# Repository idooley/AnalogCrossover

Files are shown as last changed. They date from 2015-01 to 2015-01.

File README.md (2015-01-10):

## Overview
This repo contains various things that were used to help in the design and building of an analog active 3-way 12dB/octave crossover (woofer, midrange, tweeter) with delays. In my project I configure the circuits to crossover at 125Hz and 2.7KHz. The crossover can be adapted to any audio frequencies by changing the capacitor and resistor values.

Some things you'll find in the repo:
* python utilities for help in selecting optimal capacitor and resistor values for a Sallen-Key topology active filter. To crossover at different frequencies, different combinations of resistors and capactitors may be used. Lower value resistors will reduce the Johnson Noise introduced into the signal by the resistors. Lower valued capacitors are likely to be cheaper. Finding a good combination of values that produce the desired crossover frequencies is a non-trivial exercise.
* DipTrace schematic files and PCB layouts
* PCB gerbers (both for the crossover circuit PCB and a corresponding dual-rail power supply)
* Pictures of the results
* LTSpice files for parts of the crossover design
* Bill Of Materials containing DigiKey part numbers that I used in this DIY project

## Background
The design is based off a design contained in <a href="http://www.amazon.com/Design-Active-Crossovers-Douglas-Self/dp/0240817389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">Douglas Self's excellent book "The Design of Active Crossovers"</a>.

The crossover can use either the solid NE5532 opamps or 10x more expensive, and more modern, LM4562 opamps (or a combination of both). I chose to use the LM4562's for the input stage and NE5532's for the filter and delay stages.
 
## Isaac's DIY Project

The nearly final product of this DIY product consists of these two working crossover/delay boards and their power supply:

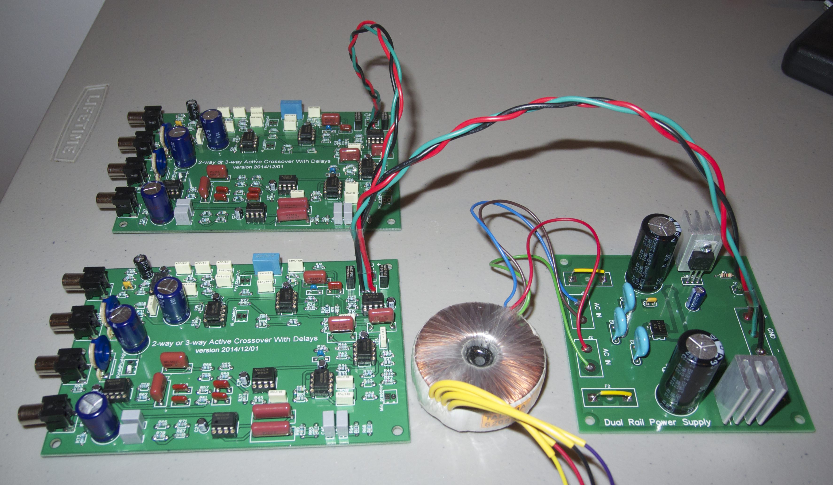
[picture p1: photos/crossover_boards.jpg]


Now I just need to put these in an enclosure of some kind (and add those two missing fuses you may have noticed in the picture). After doing this I'll measure the frequency response and noise floor more carefully.

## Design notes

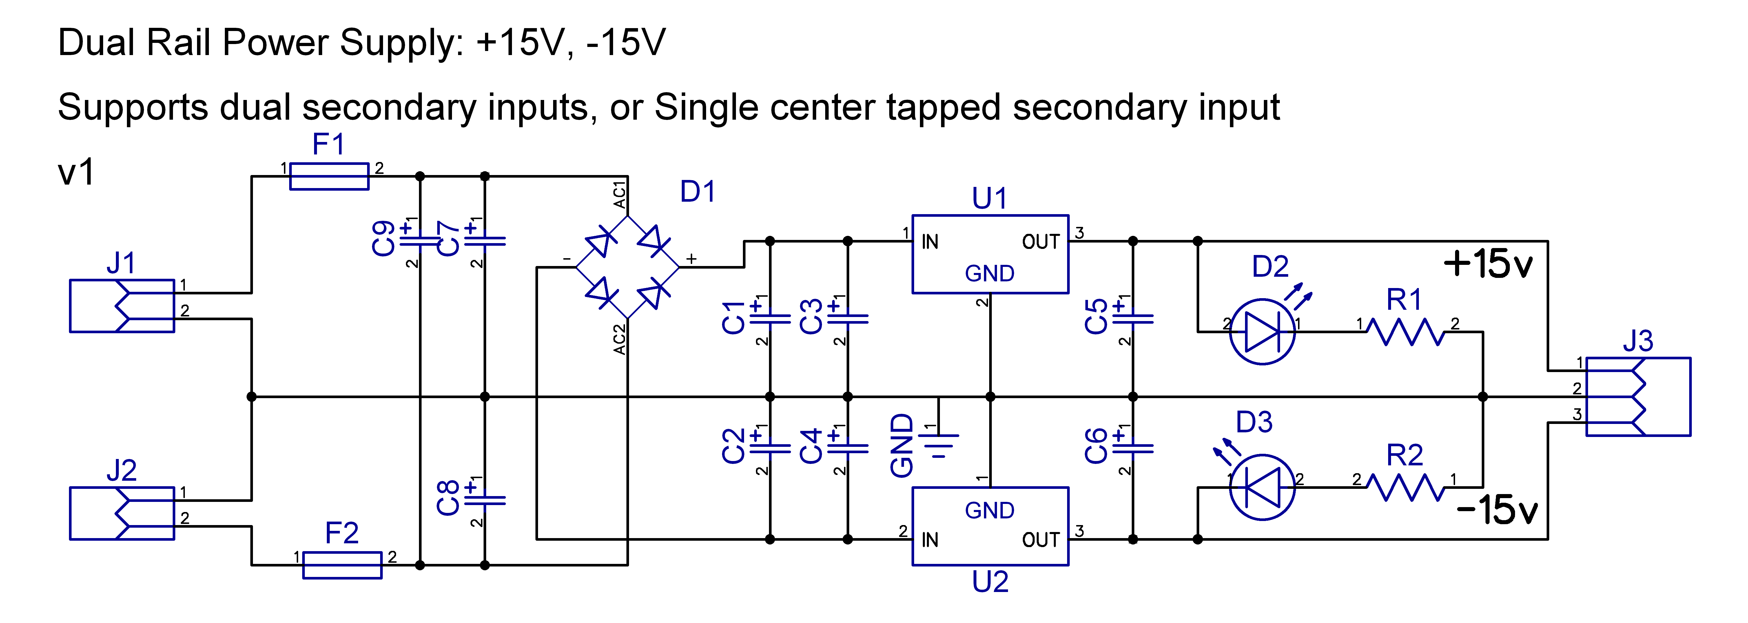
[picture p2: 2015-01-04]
power supply schematic.png

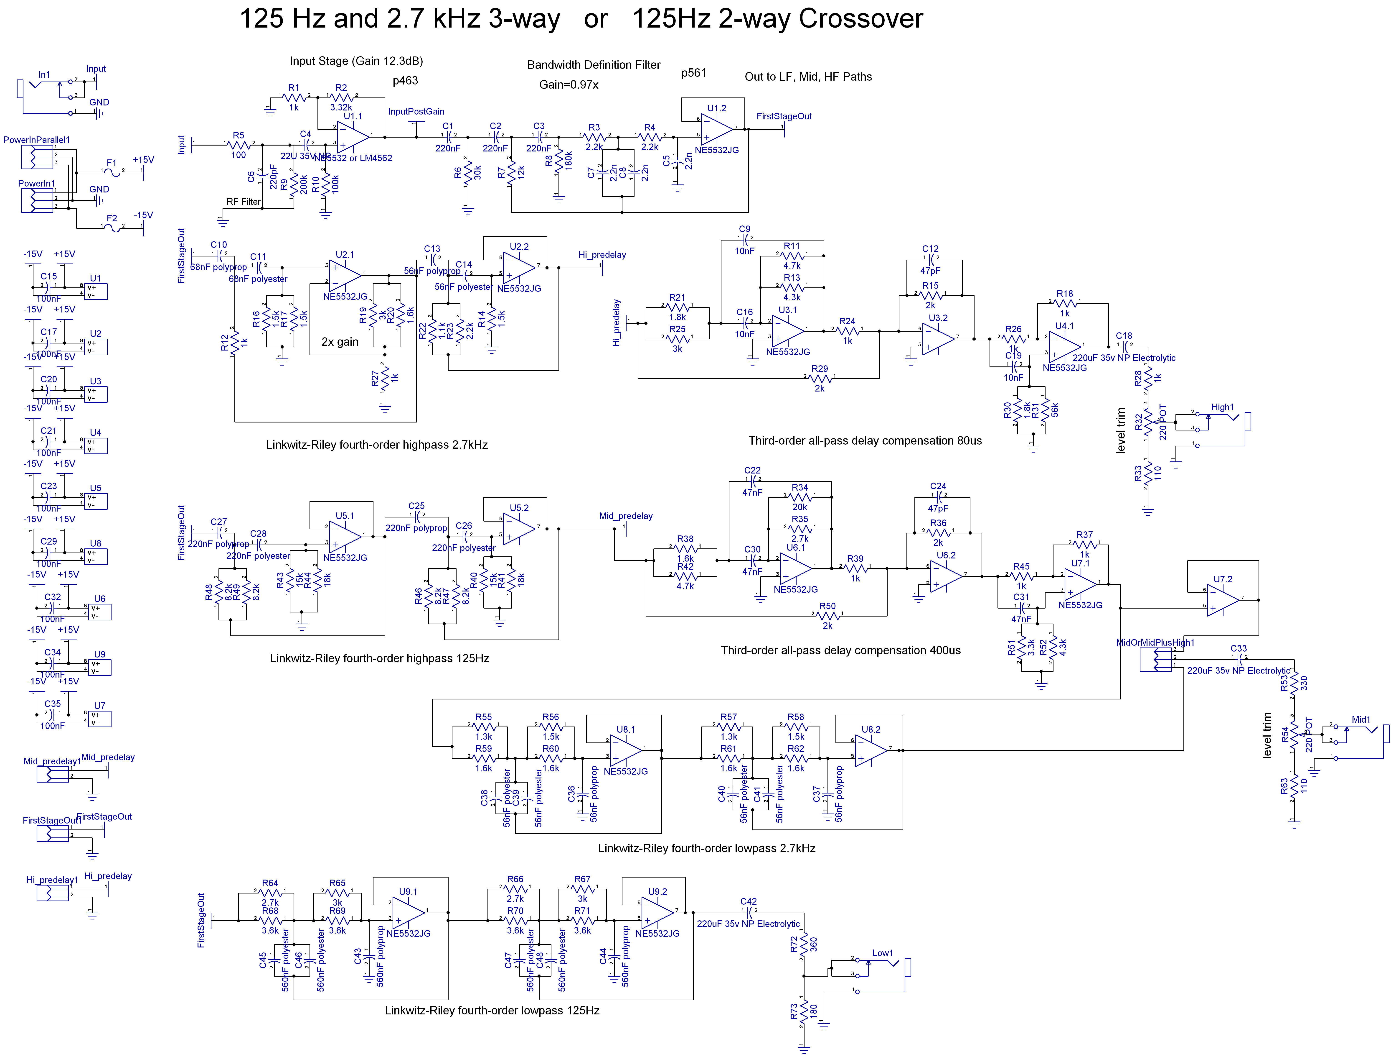
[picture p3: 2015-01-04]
schematic-800dpi.png

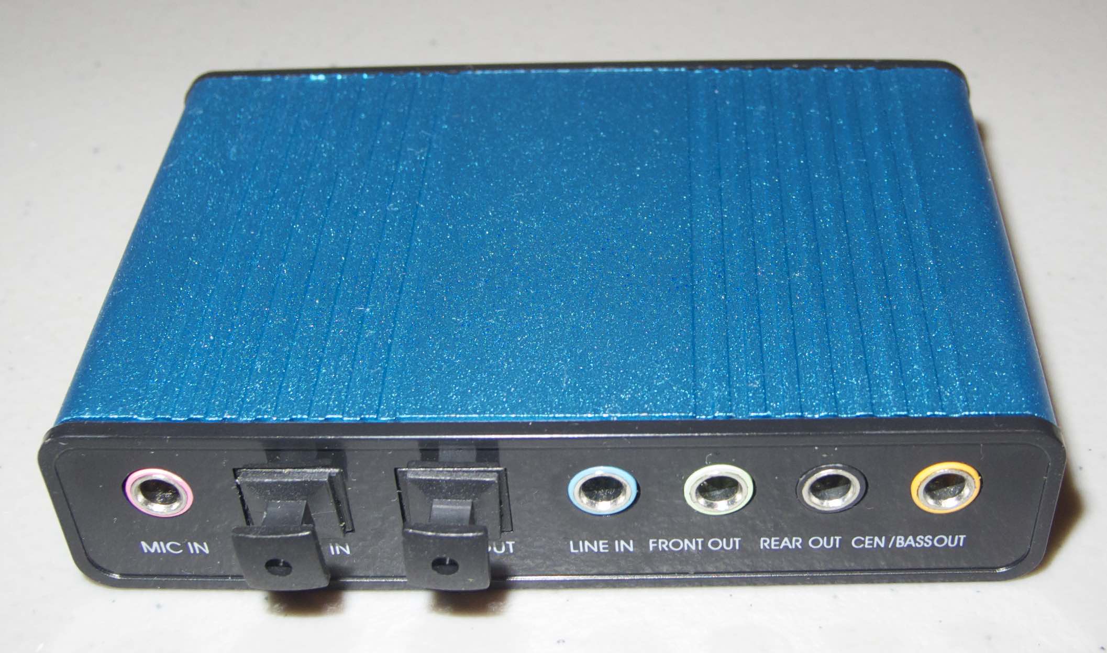
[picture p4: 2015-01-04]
photos/USB_SoundCard.jpg

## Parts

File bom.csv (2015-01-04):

RefDes | Value | Part
C1 | 220nF | 399-9686-ND
C2 | 220nF | 399-9686-ND
C3 | 220nF | 399-9686-ND
C4 | 22U 35V NP | 493-6093-ND
C5 | 2.2n | 399-9692-1-ND
C6 | 220pF | 478-4847-ND
C7 | 2.2n | 399-9692-1-ND
C8 | 2.2n | 399-9692-1-ND
C9 | 10nF | 399-5872-ND
C10 | 68nF polyprop | 495-1292-ND
C11 | 68nF polyester | 399-6036-ND
C12 | 47pF | 445-4722-ND
C13 | 56nF polyprop | P12080-ND
C14 | 56nF polyester | P4522-ND
C15 | 100nF | 493-5955-ND
C16 | 10nF | 399-5872-ND
C17 | 100nF | 493-5955-ND
C18 | 220uF 35v NP Electrolytic | P1192-ND
C19 | 10nF | 399-5872-ND
C20 | 100nF | 493-5955-ND
C21 | 100nF | 493-5955-ND
C22 | 47nF | 399-5873-ND
C23 | 100nF | 493-5955-ND
C24 | 47pF | 445-4722-ND
C25 | 220nF polyprop | P16711-ND
C26 | 220nF polyester | 399-9686-ND
C27 | 220nF polyprop | P16711-ND
C28 | 220nF polyester | 399-9686-ND
C29 | 100nF | 493-5955-ND
C30 | 47nF | 399-5873-ND
C31 | 47nF | 399-5873-ND
C32 | 100nF | 493-5955-ND
C33 | 220uF 35v NP Electrolytic | P1192-ND
C34 | 100nF | 493-5955-ND
C35 | 100nF | 493-5955-ND
C36 | 56nF polyprop | P12080-ND
C37 | 56nF polyprop | P12080-ND
C38 | 56nF polyester | P4522-ND
C39 | 56nF polyester | P4522-ND
C40 | 56nF polyester | P4522-ND
C41 | 56nF polyester | P4522-ND
C42 | 220uF 35v NP Electrolytic | P1192-ND
C43 | 560nF polyprop | PCF1604-ND
C44 | 560nF polyprop | PCF1604-ND
C45 | 560nF polyester | BC1634-ND
C46 | 560nF polyester | BC1634-ND
C47 | 560nF polyester | BC1634-ND
C48 | 560nF polyester | BC1634-ND
F1 |  | 507-1173-ND
F2 |  | 507-1173-ND
High1 |  | PJRAN1X1U01X
In1 |  | PJRAN1X1U01X
Low1 |  | PJRAN1X1U01X
Mid1 |  | PJRAN1X1U01X
R1 | 1k | RNF18FTD1K00CT-ND
R2 | 3.32k | RNF18FTD3K32CT-ND
R3 | 2.2k | S2.2KCACT-ND
R4 | 2.2k | S2.2KCACT-ND
R5 | 100 | RNF18FTD100RCT-ND
R6 | 30k | S30KCACT-ND
R7 | 12k | S12KCACT-ND
R8 | 180k | S180KCACT-ND
R9 | 200k | RNF18FTD200KCT-ND
R10 | 100k | RNF18FTD100KCT-ND
R11 | 4.7k | S4.7KCACT-ND
R12 | 1k | RNF18FTD1K00CT-ND
R13 | 4.3k | S4.3KCACT-ND
R14 | 1.5k | S1.5KCACT-ND
R15 | 2k | S2KCACT-ND
R16 | 1.5k | S1.5KCACT-ND
R17 | 1.5k | S1.5KCACT-ND
R18 | 1k | RNF18FTD1K00CT-ND
R19 | 3k | S3KCACT-ND
R20 | 1.6k | S1.6KCACT-ND
R21 | 1.8k | S1.8KCACT-ND
R22 | 1.1k | S1.1KCACT-ND
R23 | 2.2k | S2.2KCACT-ND
R24 | 1k | RNF18FTD1K00CT-ND
R25 | 3k | S3KCACT-ND
R26 | 1k | RNF18FTD1K00CT-ND
R27 | 1k | RNF18FTD1K00CT-ND
R28 | 1k | RNF18FTD1K00CT-ND
R29 | 2k | S2KCACT-ND
R30 | 1.8k | S1.8KCACT-ND
R31 | 56k | S56KCACT-ND
R32 | 220 POT | 201XR251B-ND
R33 | 110 | S110CACT-ND
R34 | 20k | S20KCACT-ND
R35 | 2.7k | S2.7KCACT-ND
R36 | 2k | S2KCACT-ND
R37 | 1k | RNF18FTD1K00CT-ND
R38 | 1.6k | S1.6KCACT-ND
R39 | 1k | RNF18FTD1K00CT-ND
R40 | 15k | S15KCACT-ND
R41 | 18k | S18KCACT-ND
R42 | 4.7k | S4.7KCACT-ND
R43 | 15k | S15KCACT-ND
R44 | 18k | S18KCACT-ND
R45 | 1k | RNF18FTD1K00CT-ND
R46 | 8.2k | S8.2KCACT-ND
R47 | 8.2k | S8.2KCACT-ND
R48 | 8.2k | S8.2KCACT-ND
R49 | 8.2k | S8.2KCACT-ND
R50 | 2k | S2KCACT-ND
R51 | 3.3k | S3.3KCACT-ND
R52 | 4.3k | S4.3KCACT-ND
R53 | 330 | S330CACT-ND
R54 | 220 POT | 201XR251B-ND
R55 | 1.3k | S1.3KCACT-ND
R56 | 1.5k | S1.5KCACT-ND
R57 | 1.3k | S1.3KCACT-ND
R58 | 1.5k | S1.5KCACT-ND
R59 | 1.6k | S1.6KCACT-ND
R60 | 1.6k | S1.6KCACT-ND
R61 | 1.6k | S1.6KCACT-ND
R62 | 1.6k | S1.6KCACT-ND
R63 | 110 | S110CACT-ND
R64 | 2.7k | S2.7KCACT-ND
R65 | 3k | S3KCACT-ND
R66 | 2.7k | S2.7KCACT-ND
R67 | 3k | S3KCACT-ND
R68 | 3.6k | S3.6KCACT-ND
R69 | 3.6k | S3.6KCACT-ND
R70 | 3.6k | S3.6KCACT-ND
R71 | 3.6k | S3.6KCACT-ND
R72 | 360 | S360CACT-ND
R73 | 180 | S180CACT-ND
U1 | NE5532 or LM4562 | LM4562NA/NOPB-ND
U2 | NE5532 | 296-1410-5-ND
U3 | NE5532 | 296-1410-5-ND
U4 | NE5532 | 296-1410-5-ND
U5 | NE5532 | 296-1410-5-ND
U6 | NE5532 | 296-1410-5-ND
U7 | NE5532 | 296-1410-5-ND
U8 | NE5532 | 296-1410-5-ND
U9 | NE5532 | 296-1410-5-ND
socket |  | ED60000-ND
socket |  | ED60000-ND
socket |  | ED60000-ND
socket |  | ED60000-ND
socket |  | ED60000-ND
socket |  | ED60000-ND
socket |  | ED60000-ND
socket |  | ED60000-ND
socket |  | ED60000-ND

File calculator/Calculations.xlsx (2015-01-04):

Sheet: Sallen-Key Unity Gain High Pass
 | High Pass wikipedia example | High Pass (example in book) | Target |  | Ideal based on http://www.calculatoredge.com/electronics/sk%20high%20pass.htm
 |  | 3000 | 2700 | 2700 | 3000 | 2700 | 2700 | 2700 | 125
R1 | 10000 | 800 | 750 | 600 | 797.5 | 886.525 | 744.0475 | 733.3333333 | 4100
R2 | 10000 | 1600 | 1500 | 1200 | 1595 | 1773.05 | 1488.095 | 1500 | 8200
C1 | 2.2e-07 | 4.7e-08 | 5.6e-08 | 6.8e-08 | 4.7e-08 | 4.7e-08 | 5.6e-08 | 5.6e-08 | 2.2e-07
C2 | 2.2e-07 | 4.7e-08 | 5.6e-08 | 6.8e-08 | 4.7e-08 | 4.7e-08 | 5.6e-08 | 5.6e-08 | 2.2e-07
Q | 0.5 | 0.7071067812 | 0.7071067812 | 0.7071067812 | 0.7071067812 | 0.7071067812 | 0.7071067812 | 0.7150969419 | 0.7071067812
w0 | 454.5454545 | 18806.03141 | 16835.87574 | 17331.04856 | 18864.98449 | 16970.55935 | 16970.56546 | 17026.11767 | 783.9321299
f0 | 72.34315594 | 2993.072859 | 2679.512845 | 2758.322047 | 3002.455533 | 2700.948408 | 2700.94938 | 2709.790788 | 124.7666735
1/sqrt(2) | 0.7071067812 | 0.7071067812 | 0.7071067812 | 0.7071067812 | 0.7071067812 | 0.7071067812 | 0.7071067812 | 0.7071067812 | 0.7071067812
 |  | 1596.305525
 |  |  |  |  | http://en.wikipedia.org/wiki/Sallen%E2%80%93Key_topology

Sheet: Sallen-Key High Pass
Goal | 3000 | 2700 | 2700
C1 | 4.7e-08 | 8.2e-08 | 6.8e-08
C2 | 4.7e-08 | 8.2e-08 | 6.8e-08
R1 | 960 | 620 | 750
R2 | 1300 | 820 | 1000
R3 | 1000 | 820 | 1000
R4 | 1080 | 820 | 1043.478261
K | 2.08 | 2 | 2.043478261
f | 3031.202669 | 2722.096404 | 2702.592585
q | 0.7146489275 | 0.6990409204 | 0.7113780103
q - 1/sqrt(2) | 0.007542146335 | -0.008065860795 | 0.004271229065

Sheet: Sallen-Key Unity Gain low Pass
 | High Pass wikipedia example
Target F | 10000 | 3000
R1 | 10000 | 717.2413793
R2 | 10000 | 888.8888889
C1 | 1e-09 | 9.4e-08
C2 | 1e-09 | 4.7e-08
Q | 0.5 | 0.7030571649
w0 | 100000 | 18842.16215
f0 | 15915.49431 | 2998.823245
1/sqrt(2) | 0.7071067812 | 0.7071067812
 |  |  | http://en.wikipedia.org/wiki/Sallen%E2%80%93Key_topology
